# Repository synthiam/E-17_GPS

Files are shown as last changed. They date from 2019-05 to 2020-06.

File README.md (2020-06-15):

# E-17 GPS

**Project Status:** Prototype

If you are new to GitHub and would like to create a derivative of this project, please have a look at GitHub instructions to [fork a repo](https://help.github.com/en/articles/fork-a-repo)

## Description

Out of our passion to solve the issue of time waste in the robot creation process, ARC was born. The ARC software platform reduces the time it takes to get from idea to implementation. Since 2011 we have been listening to the challenges robot builders encounter and continue to provide them with an ever expanding toolbox of solutions. Join us on this journey!

We didn't stop at the software, we also made time saving hardware solutions. This GPS design is one of them. This is a ez-clip mounting option for the Waveshare GPS NEO-7M-C module. A unique feature of this design is that it allows the GPS antenna to keep pointing skyward while the module is mounted onto a vertical connection. We want to share these files with you so you can create your own version for your community and customers to enjoy!

**Features:**
- UART communication
- On-board GPS antenna
- PPS pin broken out
- Backup battery and EEPROM
- 3.3V voltage regulator 
- Red status LED
- Voltage requirements: 3.2-5V (3.3V typical)
- Current draw: 78mA
- Dimensions: 25.5(W) x 35.3(L) x 37.5(H) (mm)
- Weight: 20g

**Major components:** 
- NEO-7M-C GPS module

**Manufacturing notes:** 
1. Manufacturer: Dual side placement and soldering of PCBs

Wiki link for NEO-7M-C module: https://www.waveshare.com/wiki/UART_GPS_NEO-7M-C

## Contents

[**Documentation:**](https://github.com/synthiam/E-17_GPS/tree/master/E-17%20Documentation) BOM, Assembly Notes

[**Hardware:**](https://github.com/synthiam/E-17_GPS/tree/master/E-17%20Hardware) Altium PCB design Files

*Altium Libraries are also available <a href="https://github.com/synthiam/Synthiam_Altium_Librairies">here</a>*

## Photos

<p align="left">

</p>

## ARC GPS Skill

The ARC skill for this reference design is very easy to use! Simply click on the connect button to get GPS Latitude, Longitude, time, speed, altitude, and satelitte count. 

Link: https://synthiam.com/Software/Manual/GPS-16145

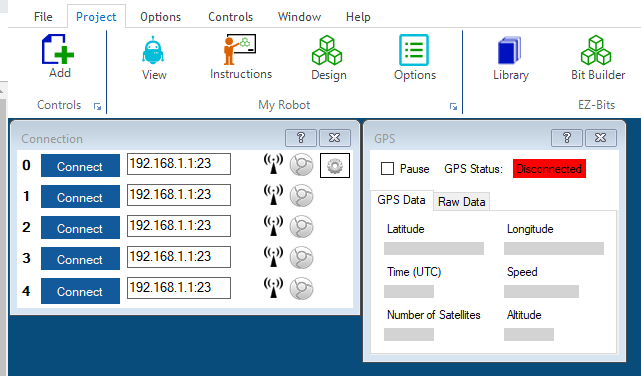
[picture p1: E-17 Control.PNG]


## Contact

For profit use of these files requires written consent. Contact partners@synthiam.com. For everyone else, party on!

Synthiam Website: https://synthiam.com

## License

This project is released under the following license:

**Hardware:** Creative Commons Plus Attribution-NonCommercial 4.0 International (CC+ BY-NC 4.0)

Please see [LICENSE.md](https://github.com/synthiam/E-17_GPS/blob/master/LICENSE.md) for license details.



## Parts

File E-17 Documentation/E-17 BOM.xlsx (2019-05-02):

Qty | Description | Manufacturer Part No. | Alternative | Designator | Custom Information | Link
E-17 GPS
1 | 2 layer, Blue soldermask, White silkscreen, ENIG | Ez-bit PCB |  | PCB
1 | 2 layer, Blue soldermask, White silkscreen, ENIG | Spacer PCB |  | PCB2
1 | NEO-7M-C GPS from Waveshare | UART GPS NEO-7M-C |  | U1 |  | http://www.waveshare.com/uart-gps-neo-7m-c.htm
1 | 4 position 0.1" spacing Right angle Female header | PPTC041LGBN-RC |  | P2 |  | https://www.digikey.ca/product-detail/en/sullins-connector-solutions/PPTC041LGBN-RC/S5440-ND/775898

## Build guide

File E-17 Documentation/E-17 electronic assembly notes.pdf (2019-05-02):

# Assembly Instructions PARTS & TOOLS

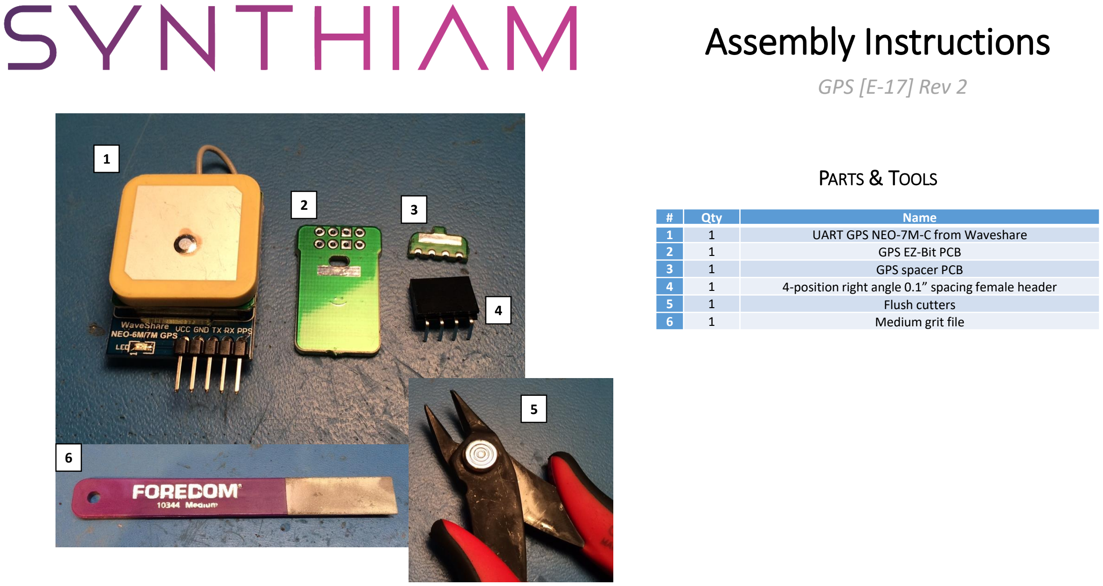
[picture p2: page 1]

# | Qty | Name 1 | 1 | UART GPS NEO-7M-C from Waveshare 2 | 1 | GPS EZ-Bit PCB 3 | 1 | GPS spacer PCB 4 | 1 | 4-position right angle 0.1” spacing female header 5 | 1 | Flush cutters 6 | 1 | Medium grit file

GPS

[E

-17] Rev

2

1

2
3

4

5

6

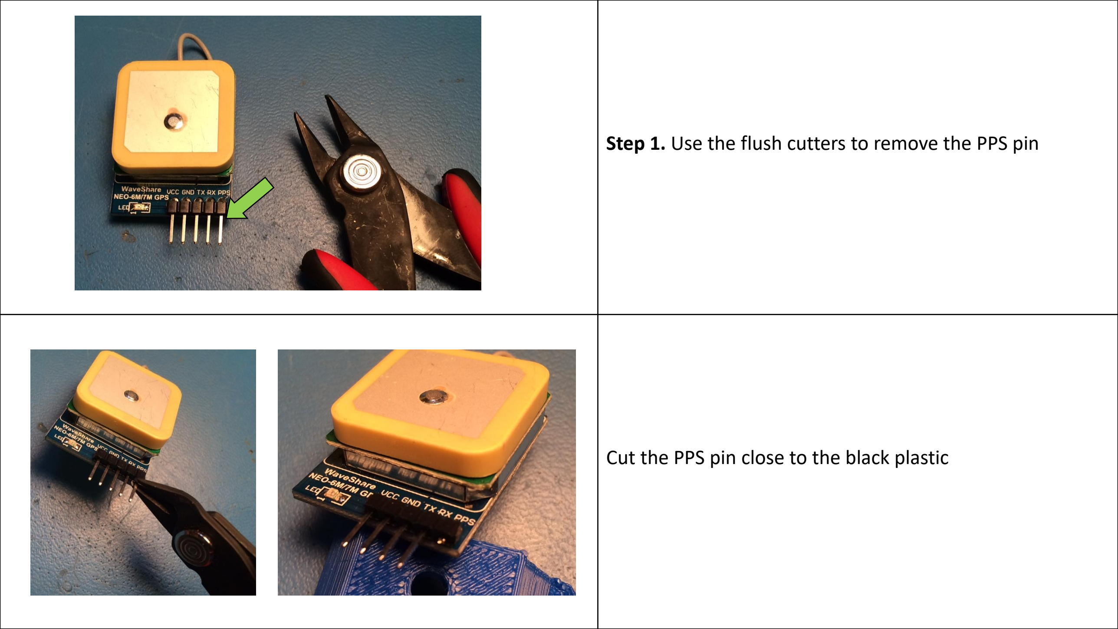
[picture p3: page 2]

Step 1. Use the flush cutters to remove the PPS pin

Cut the PPS pin close to the black plastic

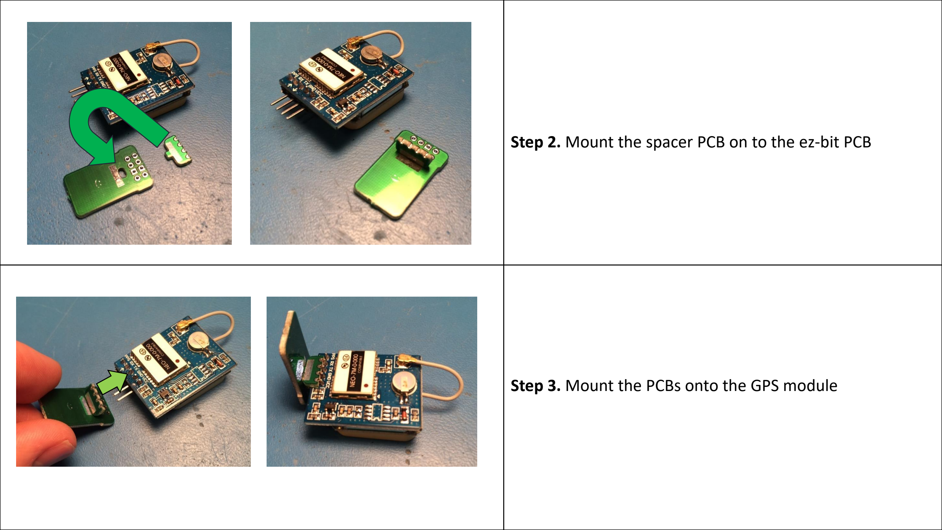
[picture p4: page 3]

Step 2. Mount the spacer PCB on to the ez-bit PCB
Step 3. Mount the PCBs onto the GPS module

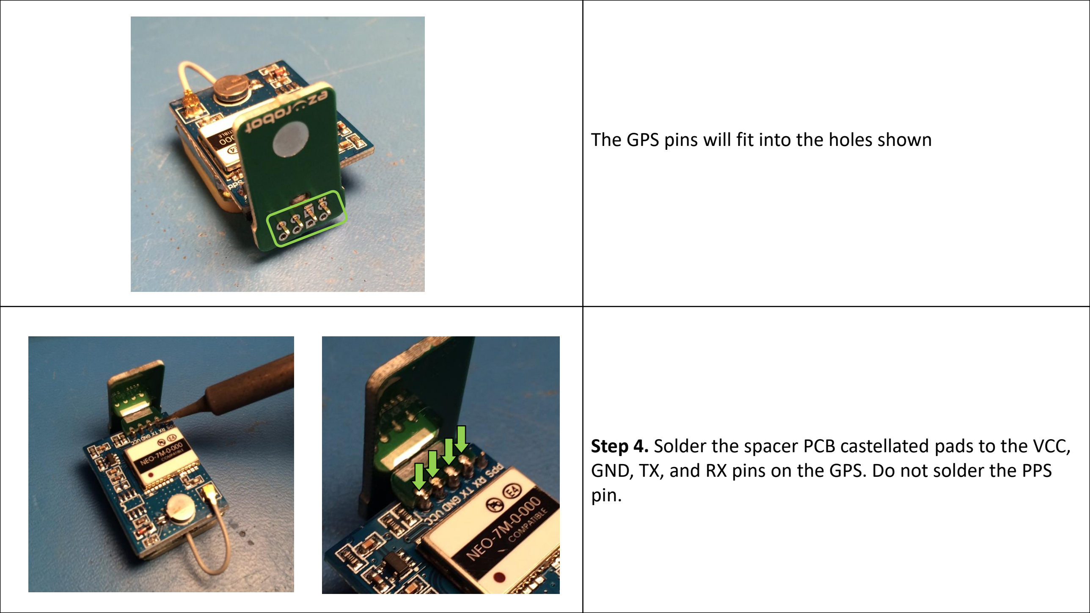
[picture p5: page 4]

The GPS pins will fit into the holes shown

Step 4. Solder the spacer PCB castellated pads to the VCC, GND, TX, and RX pins on the GPS. Do not solder the PPS pin.

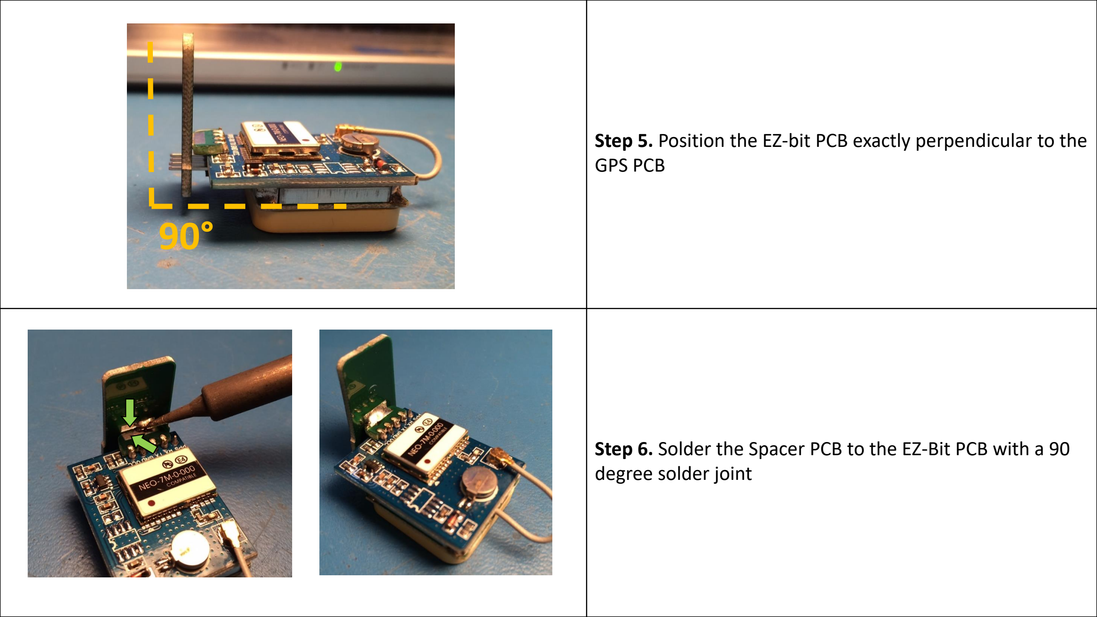
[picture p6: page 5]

Step 5. Position the EZ-bit PCB exactly perpendicular to the GPS PCB
Step 6. Solder the Spacer PCB to the EZ-Bit PCB with a 90 degree solder joint

90°

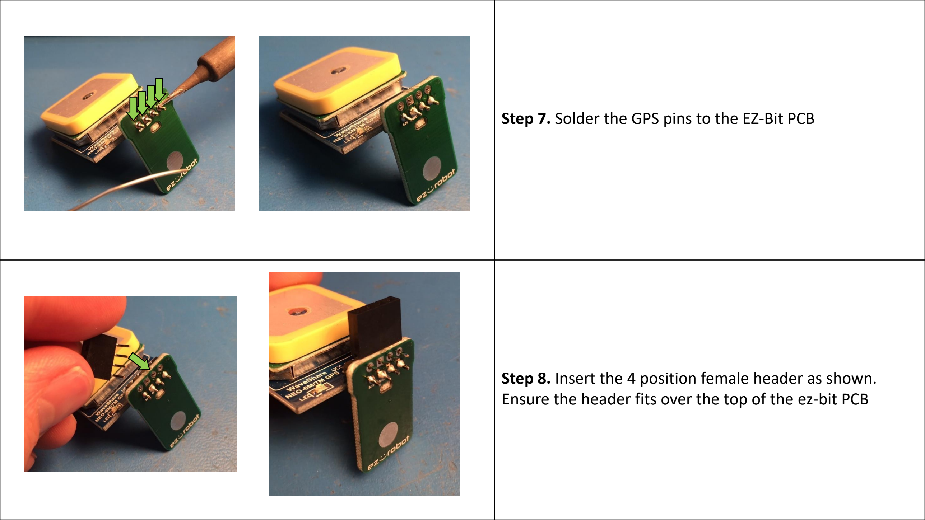
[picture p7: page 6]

Step 7. Solder the GPS pins to the EZ-Bit PCB
Step 8. Insert the 4 position female header as shown. Ensure the header fits over the top of the ez-bit PCB

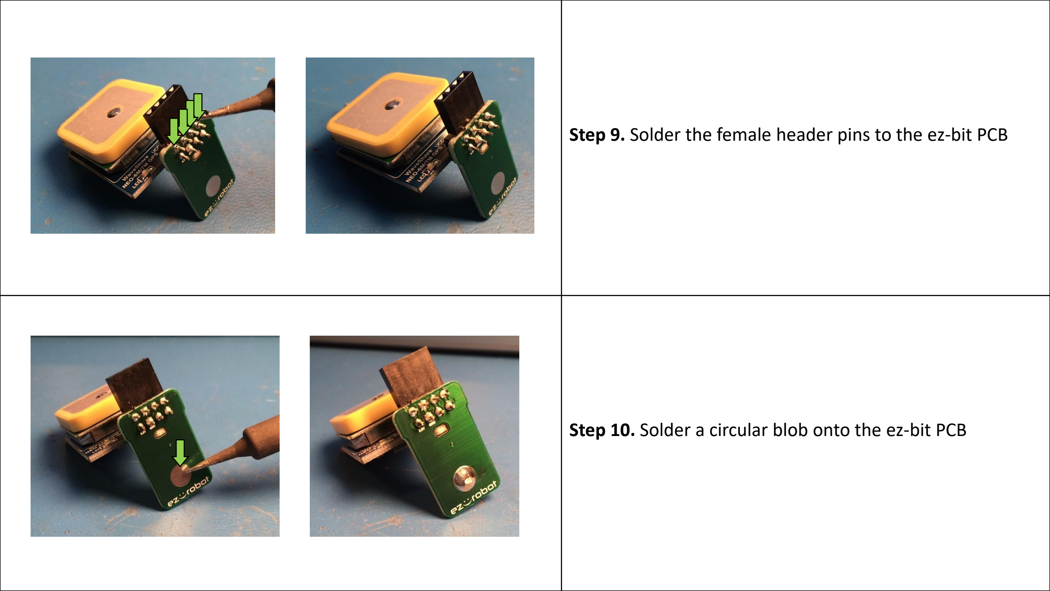
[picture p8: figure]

Step 9. Solder the female header pins to the ez-bit PCB
Step 10. Solder a circular blob onto the ez-bit PCB

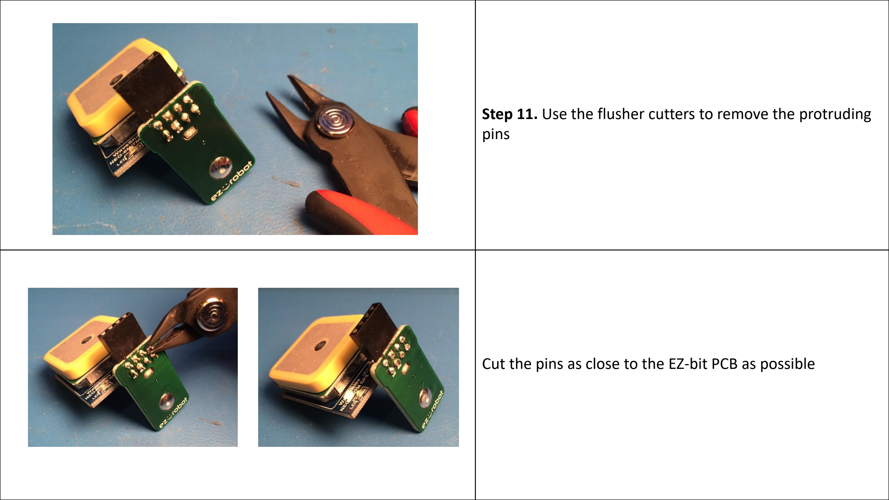
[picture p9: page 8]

Step 11. Use the flusher cutters to remove the protruding pins

Cut the pins as close to the EZ-bit PCB as possible

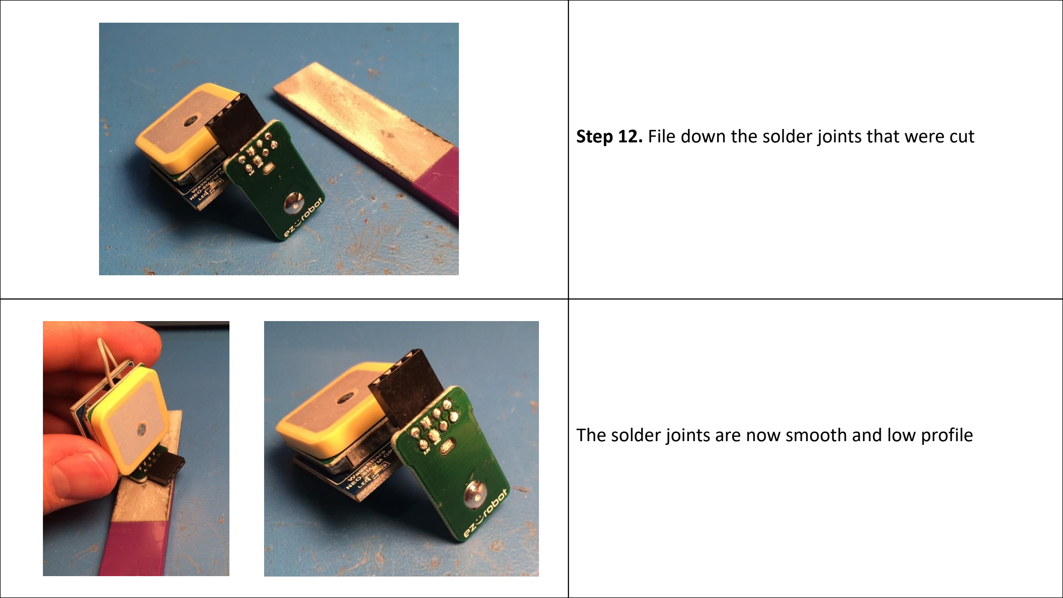
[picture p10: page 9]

Step 12. File down the solder joints that were cut

The solder joints are now smooth and low profile

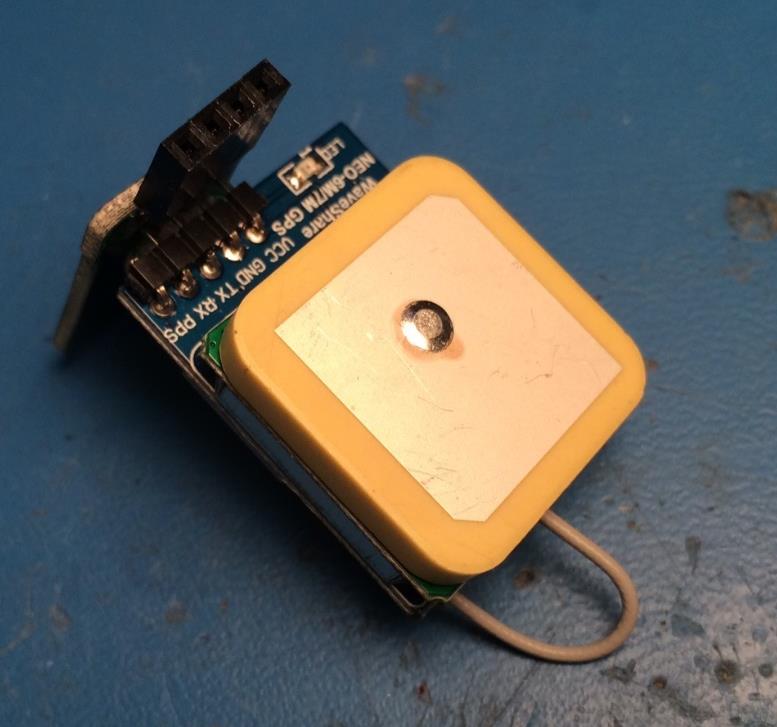
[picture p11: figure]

The GPS ez-bit has now been completed! Great work!

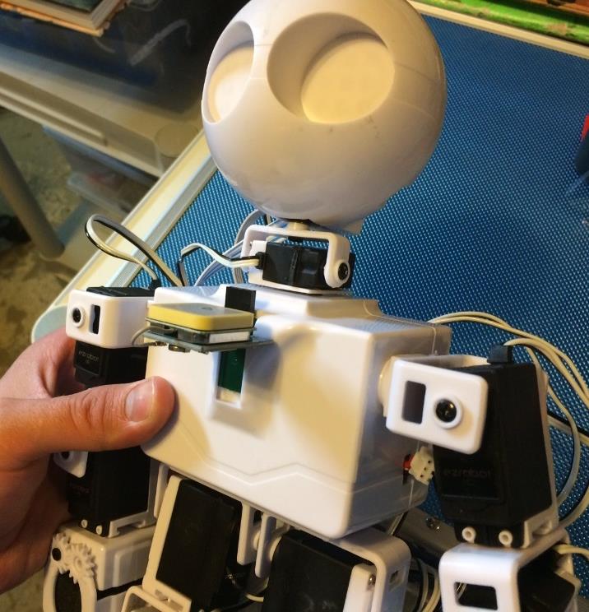
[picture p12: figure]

The GPS ez-bit can be clipped onto a robot as shown
